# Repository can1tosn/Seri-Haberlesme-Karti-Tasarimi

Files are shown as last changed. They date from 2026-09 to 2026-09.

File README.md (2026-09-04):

# Seri-Haberlesme-Karti-Tasarimi
Altium Designer ile tasarlanmış; STM32F437 mikrodenetleyici tabanlı, çoklu haberleşme arayüzlerine (RS-485, RS-232, CAN Bus, Ethernet) ve RT7235 buck konvertör güç katına sahip 4 katmanlı endüstriyel donanım kartı tasarımı.

# Çoklu Arayüzlü Endüstriyel Haberleşme Kartı

Bu depo, RST Teknoloji'deki mühendislik stajım kapsamında Altium Designer kullanılarak sıfırdan tasarlanmış endüstriyel bir donanım kartına ait şematik, PCB dizgi (4-katman), üretim ve 3D model dosyalarını içermektedir.

## 🛠️ Donanım Özellikleri ve Temel Bileşenler
* **Mikrodenetleyici:** STM32F437 (Yüksek performanslı ARM Cortex-M4 çekirdek)
* **Güç Katı (Power Management):** RT7235GQW Senkron Buck Konvertör (12V giriş, kararlı 5V/3.3V çıkış, özel soft-start ve bootstrap filtrelemeli tasarım)
* **Endüstriyel Haberleşme Arayüzleri:** 
  * RS-485 / RS-422 (SN65HVD78DRBT transceiver ile 120 Ohm sonlandırmalı empedans kontrolü)
  * RS-232 (Çift kanallı iletişim)
  * CAN Bus (Otomotiv ve endüstri standartlarında veri yolu)
* **Ağ Bağlantısı:** LAN8742A Ethernet PHY (25 MHz yüksek kararlılıklı C0G kristal osilatör devresi ile)
* **Çevresel Sensörler:** BME280 (I2C/SPI destekli sıcaklık, nem ve basınç sensörü)

## 📂 Depo İçeriği ve İnceleme Dosyaları
Bu proje, sadece donanım mühendislerinin değil; yazılım, mekanik ve test ekiplerinin de kolayca inceleyebileceği evrensel formatları barındırır:

* **Altium Kaynak Dosyaları:** Geliştirmeye açık güncel şematik (`.SchDoc`), 4-katmanlı PCB (`.PcbDoc`) ve projeye özel kütüphane dosyaları.
* **BOM (Malzeme Listesi):** Üretim optimizasyonu (BOM Consolidation) sağlamak amacıyla pasif bileşenler ve yüksek hassasiyetli elemanlarla hazırlanmış üretime hazır Excel listesi.
* **📄 Akıllı PDF (Smart PDF):** Bilgisayarında Altium Designer kurulu olmayan kişilerin şematikleri interaktif olarak inceleyebilmesi için oluşturulmuştur. (*PDF üzerinden pinlere veya komponentlere tıklayarak bağlantıları (net) takip edebilirsiniz.*)
* **🧊 3D STEP Modeli:** Kartın mekanik (kutu içi) entegrasyon testleri ve SolidWorks gibi CAD programlarında incelenebilmesi için `.step` formatında 3 boyutlu katı modeli.

## 🔍 Tarayıcı Üzerinden İnteraktif İnceleme (Program Kurulumsuz)
Bilgisayarınıza herhangi bir program indirmeden projenin 3 boyutlu halini ve PCB katman yollarını incelemek isterseniz:
1. Depodaki kaynak dosyaları bilgisayarınıza indirin (ZIP olarak).
2. [Altium 365 Online Viewer](https://www.altium.com/viewer/) adresine gidin.
3. Dosyaları ekrana sürükleyip bırakarak projeyi web tarayıcınız üzerinden tüm detaylarıyla inceleyin.

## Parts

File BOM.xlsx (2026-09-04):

Designator | Description | MPN | Quantity
B1 | TRANS NPN 40V 0.2A SOT23-3 | MMBT3904 | 1
C1, C8 | CON SMD 402 | CL05A104KA5NNNC | 2
C2, C3, C4, C5, C6, C7, C11, C16, C19, C20, C21, C31, C33 | CAP SMD 402 | CL05A104KA5NNNC | 13
C9, C10, C24 | CON SMD 0603 | GRM188R61E106MA73D | 3
C12 | CAP SMD 402 | C0603C392J3GACTU | 1
C13, C14 | CAP SMD 0805 | CL10A226MO7JZNC | 2
C15 | CAP SMD 402 | C0402C153J5RECTU | 1
C17, C23, C53, C54, C61 | CAP SMD 402 | GRM155R6YA105KE11D | 5
C18, C63 | CON SMD 402 | CL05A104KA5NNNC | 2
C22, C32 | CAP SMD 402 | C1005X5R1V225K050BC | 2
C25 | CAP SMD 402 | C0402C103K5RECAUTO | 1
C26, C27 | CAP SMD 402 | GCM1555C1H470JA16D | 2
C28, C30, C36, C37, C38, C39, C40, C41, C42, C43, C44, C45, C46, C47, C48, C50, C51, C52, C55, C56, C57, C58 | CAP SMD 402 | CL05A104KA5NNNC | 22
C29 | CAP SMD 0603 | GRM188R61E475KE11D | 1
C34, C35, C59, C62 | CAP SMD 402 | GRM1555C1H150JA01D | 4
C49 | CAP SMD 0603 | GRM188R61E106MA73D | 1
C60 | CAP SMD 402 | GRM1555C1H471JA01D | 1
C64 | CAP SMD 402 | C0402C472K5RECAUTO | 1
D1, D2, D3, D4, D5 | LED RED CLEAR 0603 SMD | 150060RS75000 | 5
D6 | DIODE SCHOTTKY 40V 1A DO214AC | SS14 | 1
J1 | CONN HEADER R/A 8POS 2.54MM | 0901362108 | 1
J2, J3, J7, J8 | CONN HEADER R/A 2POS 2.54MM | 0901362102 | 4
J4, J6 | CONN HEADER R/A 4POS 2.54MM | 0901362104 | 2
J5 | CONN RCPT USB2.0 TYPEA 4P SMD RA | 87583-3010RPALF | 1
J9 | CONN JACK 1PORT PCB | ARJM11C7-009-AB-EW2 | 1
J10 | CONN RCPT USB2.0 MICRO B SMD R/A | 10118192-0001LF | 1
J11 | CONN HEADER R/A 2POS 2.54MM | 0901362102 | 1
J12 | CONN HEADER R/A 10POS 2.54MM | 0901362110 | 1
J13 | WR-PHD 2.54 MM SOCKET HEADER 4 P | 61300411821 | 1
L1 | FIXED IND 2.2UH 850MA 175.5 MOHM | BRL2518T2R2M | 1
M1 | MOSFET N-CH 12V 2.1A 3PICOSTAR | IRLML6402 | 1
R1 | RES SMD 0402 |  | 1
R2 | RES SMD 0402 | ERJ-2RKF1003X | 1
R3 | RES SMD 0402 | ERA-2AEB183X | 1
R4, R5, R12 | RES SMD 0402 | ERJ-2RKF1200X | 3
R6 | RES SMD 0603 | MI0603J601R-10 | 1
R7, R8 | RES SMD 0402 | RC0402FR-0727RL | 2
R9, R10, R28 | RES SMD 0402 | RMCF0402FT4K70 | 3
R11, R13, R14, R15, R16, R17, R18, R20, R29, R37 | RES SMD 0402 | RNCF0402BTE10K0 | 10
R19 | RES SMD 0402 | CR0402FC1KS001 | 1
R21, R27 | RES SMD 0402 | RMCF0402FT270R | 2
R22, R23, R24, R25 | RES SMD 0402 | RG1005N-49R9-W-T1 | 4
R26 | RES SMD 0603 | RT0603BRD0712K1L | 1
R30 | RES SMD 0402 | CR0402JC1MS001 | 1
R31 | RES SMD 0805 | RG2012L-472-L-T05 | 1
R32, R33, R34, R35, R36 | RES SMD 0402 | RC0402FR-13300RL | 5
SW2 | Tactile Switch, SPST-NO, 0.05 A, 12 V, -25 to 70 degC, 2-Pin SMD, RoHS | B3U-1000P | 1
U1 | IC TRANSCEIVER FULL 1/1 16SSOP (±5V i±15V - 3kΩ 7kΩ) | MAX3221EIDBR | 1
U2 | IC TRANSCEIVER HALF 1/1 8SON (-7V +12V - 54 Ω) | SN65HVD78DRBT | 1
U3 | IC REG BUCK ADJ 5A 10WDFN | RT7235GQW | 1
U4 | IC TRANSCEIVER 1/1 8SOIC | MCP2562FD-E/SN | 1
U5 | SENSOR PRESSURE HUMIDITY TEMP | BME280 | 1
U6 | IC TRANSCEIVER FULL 1/1 8SOIC | SP3077EEN-L | 1
U7 | MCU 32-bit STM32F ARM Cortex M4 RISC 2048KB Flash 2.5V/3.3V 144-Pin LQFP | STM32F437ZIT6 | 1
U8 | IC REG LINEAR 3.3V 500MA 6-WSON | TLV75533PDRVR | 1
U9 | IC USB SERIAL BASIC UART 12DFN (0V - 3.3V, 27Ω - 90Ω) | FT234XD-R | 1
U10 | IC TRANSCEIVER HALF 1/1 8SON | SN65HVD78DRBT | 1
U11 | IC TRANSCEIVER FULL 1/1 24SQFN | LAN8742AI-CZ-TR | 1
U12 | TVS DIODE 5.25VWM 17VC SOT23-6 | USBLC6-2SC6 | 1
U13 | IC PWR SWITCH N-CHAN 1:1 SOT23-5 | STMPS2141STR | 1
X1, X2 | CRYSTAL 25.0000MHZ 10PF SMD | RH100-25.000-10-F-1010-EXT-TR | 2

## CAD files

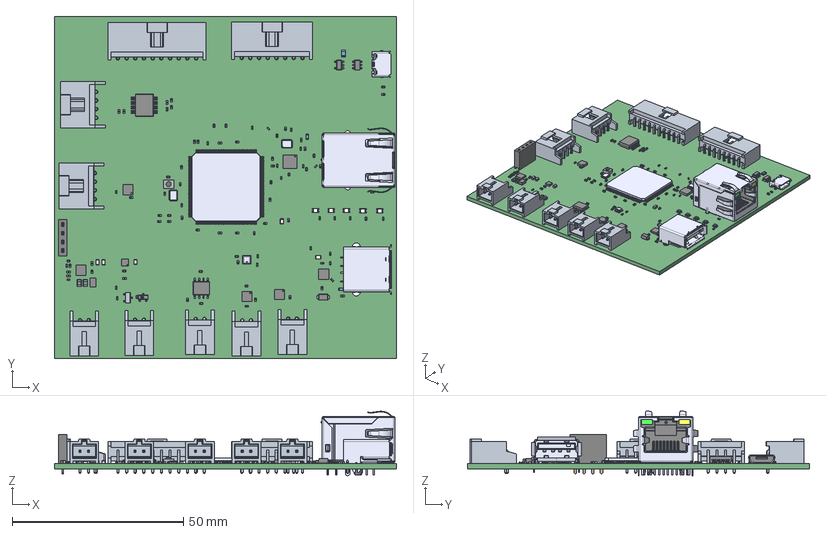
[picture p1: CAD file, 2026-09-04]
PCB1.step
100.0 x 100.0 x 18.9 mm
6130xx11821_PIN x 4
87583-2010RPLF--3DModel-STEP-533217
cap_UMK105CG080CV-F_TAY x 57
11H_HOUSING_1^11H_HOUSING_LED_ASM_7_ASM_ASM_11H_HOUSING_LED_COVER_ASM_ 1_ASM_ASM_11H_HOUSING_MODULE_ASM_1_ASM_ASM_11H_ASSEMBLE_BOTTOM_PCB_ASM_ 2_A_ASM_11H_ASSY_
11H_LED_LEFT_2^11H_HOUSING_LED_ASM_7_ASM_ASM_11H_HOUSING_LED_COVER_ASM_ 1_ASM_ASM_11H_HOUSING_MODULE_ASM_1_ASM_ASM_11H_ASSEMBLE_BOTTOM_PCB_ASM_ 2_A_ASM_11H_ASSY
11H_LED_RIGHT_3^11H_HOUSING_LED_ASM_7_ASM_ASM_11H_HOUSING_LED_COVER_ ASM_1_ASM_ASM_11H_HOUSING_MODULE_ASM_1_ASM_ASM_11H_ASSEMBLE_BOTTOM_PCB_ ASM_2_A_ASM_11H_ASS
PCB_3^PCBA_ASM_3_ASM_ASM_11H_MODULE_PCBA_ASM_3_AF0_ASM_ASM_11H_MODULE_ INSERT_ASM_5_ASM_ASM_11H_HOUSING_MODULE_ASM_1_ASM_ASM_11H_ASSEMBLE_ BOTTOM_PCB_ASM_2_A_AS
4D03_3^PCBA_ASM_3_ASM_ASM_11H_MODULE_PCBA_ASM_3_AF0_ASM_ASM_11H_MODULE_ INSERT_ASM_5_ASM_ASM_11H_HOUSING_MODULE_ASM_1_ASM_ASM_11H_ASSEMBLE_ BOTTOM_PCB_ASM_2_A_A
C_1206_3^PCBA_ASM_3_ASM_ASM_11H_MODULE_PCBA_ASM_3_AF0_ASM_ASM_11H_ MODULE_INSERT_ASM_5_ASM_ASM_11H_HOUSING_MODULE_ASM_1_ASM_ASM_11H_ ASSEMBLE_BOTTOM_PCB_ASM_2_A
MANIFOLD_SOLID_BREP_57001^CP_1_3_ASM_ASM_MODULE_CASE_11H_ASM_9_AF0_ASM_ ASM_MODULE_11H_ASM_3_AF0_ASM_ASM_11H_MODULE_PCBA_ASM_3_AF0_ASM_ASM_11H_ MODULE_INSERT_AS
MANIFOLD_SOLID_BREP_57246^CP_1_3_ASM_ASM_MODULE_CASE_11H_ASM_9_AF0_ASM_ ASM_MODULE_11H_ASM_3_AF0_ASM_ASM_11H_MODULE_PCBA_ASM_3_AF0_ASM_ASM_11H_ MODULE_INSERT_AS
MANIFOLD_SOLID_BREP_57491^CP_1_3_ASM_ASM_MODULE_CASE_11H_ASM_9_AF0_ASM_ ASM_MODULE_11H_ASM_3_AF0_ASM_ASM_11H_MODULE_PCBA_ASM_3_AF0_ASM_ASM_11H_ MODULE_INSERT_AS
MANIFOLD_SOLID_BREP_57736^CP_1_3_ASM_ASM_MODULE_CASE_11H_ASM_9_AF0_ASM_ ASM_MODULE_11H_ASM_3_AF0_ASM_ASM_11H_MODULE_PCBA_ASM_3_AF0_ASM_ASM_11H_ MODULE_INSERT_AS
MANIFOLD_SOLID_BREP_57981^CP_1_3_ASM_ASM_MODULE_CASE_11H_ASM_9_AF0_ASM_ ASM_MODULE_11H_ASM_3_AF0_ASM_ASM_11H_MODULE_PCBA_ASM_3_AF0_ASM_ASM_11H_ MODULE_INSERT_AS
MANIFOLD_SOLID_BREP_58226^CP_1_3_ASM_ASM_MODULE_CASE_11H_ASM_9_AF0_ASM_ ASM_MODULE_11H_ASM_3_AF0_ASM_ASM_11H_MODULE_PCBA_ASM_3_AF0_ASM_ASM_11H_ MODULE_INSERT_AS
MANIFOLD_SOLID_BREP_58517^CP_2_6_ASM_ASM_MODULE_CASE_11H_ASM_9_AF0_ASM_ ASM_MODULE_11H_ASM_3_AF0_ASM_ASM_11H_MODULE_PCBA_ASM_3_AF0_ASM_ASM_11H_ MODULE_INSERT_AS
MANIFOLD_SOLID_BREP_58762^CP_2_6_ASM_ASM_MODULE_CASE_11H_ASM_9_AF0_ASM_ ASM_MODULE_11H_ASM_3_AF0_ASM_ASM_11H_MODULE_PCBA_ASM_3_AF0_ASM_ASM_11H_ MODULE_INSERT_AS
MANIFOLD_SOLID_BREP_59007^CP_2_6_ASM_ASM_MODULE_CASE_11H_ASM_9_AF0_ASM_ ASM_MODULE_11H_ASM_3_AF0_ASM_ASM_11H_MODULE_PCBA_ASM_3_AF0_ASM_ASM_11H_ MODULE_INSERT_AS
MANIFOLD_SOLID_BREP_59252^CP_2_6_ASM_ASM_MODULE_CASE_11H_ASM_9_AF0_ASM_ ASM_MODULE_11H_ASM_3_AF0_ASM_ASM_11H_MODULE_PCBA_ASM_3_AF0_ASM_ASM_11H_ MODULE_INSERT_AS
MODULE_CASE_5_AF0^MODULE_CASE_11H_ASM_9_AF0_ASM_ASM_MODULE_11H_ASM_3_ AF0_ASM_ASM_11H_MODULE_PCBA_ASM_3_AF0_ASM_ASM_11H_MODULE_INSERT_ASM_5_ ASM_ASM_11H_HOUSING
CP_3_GND_1067_3^MODULE_CASE_11H_ASM_9_AF0_ASM_ASM_MODULE_11H_ASM_3_AF0_ ASM_ASM_11H_MODULE_PCBA_ASM_3_AF0_ASM_ASM_11H_MODULE_INSERT_ASM_5_ASM_ ASM_11H_HOUSING_M
MANIFOLD_SOLID_BREP_60100_AF0^CORE_T_3_AF0_ASM_ASM_COIL_ASM_3_AF0_ASM_ ASM_MODULE_11H_ASM_3_AF0_ASM_ASM_11H_MODULE_PCBA_ASM_3_AF0_ASM_ASM_11H_ MODULE_INSERT_ASM
MANIFOLD_SOLID_BREP_60561_AF0^CORE_T_3_AF0_ASM_ASM_COIL_ASM_3_AF0_ASM_ ASM_MODULE_11H_ASM_3_AF0_ASM_ASM_11H_MODULE_PCBA_ASM_3_AF0_ASM_ASM_11H_ MODULE_INSERT_ASM
MANIFOLD_SOLID_BREP_61022_AF0^CORE_T_3_AF0_ASM_ASM_COIL_ASM_3_AF0_ASM_ ASM_MODULE_11H_ASM_3_AF0_ASM_ASM_11H_MODULE_PCBA_ASM_3_AF0_ASM_ASM_11H_ MODULE_INSERT_ASM
MANIFOLD_SOLID_BREP_61483_AF0^CORE_T_3_AF0_ASM_ASM_COIL_ASM_3_AF0_ASM_ ASM_MODULE_11H_ASM_3_AF0_ASM_ASM_11H_MODULE_PCBA_ASM_3_AF0_ASM_ASM_11H_ MODULE_INSERT_ASM
MANIFOLD_SOLID_BREP_61944_AF0^CORE_T_3_AF0_ASM_ASM_COIL_ASM_3_AF0_ASM_ ASM_MODULE_11H_ASM_3_AF0_ASM_ASM_11H_MODULE_PCBA_ASM_3_AF0_ASM_ASM_11H_ MODULE_INSERT_ASM
MANIFOLD_SOLID_BREP_62405_AF0^CORE_T_3_AF0_ASM_ASM_COIL_ASM_3_AF0_ASM_ ASM_MODULE_11H_ASM_3_AF0_ASM_ASM_11H_MODULE_PCBA_ASM_3_AF0_ASM_ASM_11H_ MODULE_INSERT_ASM
MANIFOLD_SOLID_BREP_62866_AF0^CORE_T_3_AF0_ASM_ASM_COIL_ASM_3_AF0_ASM_ ASM_MODULE_11H_ASM_3_AF0_ASM_ASM_11H_MODULE_PCBA_ASM_3_AF0_ASM_ASM_11H_ MODULE_INSERT_ASM
MANIFOLD_SOLID_BREP_63327_AF0^CORE_T_3_AF0_ASM_ASM_COIL_ASM_3_AF0_ASM_ ASM_MODULE_11H_ASM_3_AF0_ASM_ASM_11H_MODULE_PCBA_ASM_3_AF0_ASM_ASM_11H_ MODULE_INSERT_ASM
MANIFOLD_SOLID_BREP_63788_AF0^CORE_T_3_AF0_ASM_ASM_COIL_ASM_3_AF0_ASM_ ASM_MODULE_11H_ASM_3_AF0_ASM_ASM_11H_MODULE_PCBA_ASM_3_AF0_ASM_ASM_11H_ MODULE_INSERT_ASM
MANIFOLD_SOLID_BREP_64249_AF0^CORE_T_3_AF0_ASM_ASM_COIL_ASM_3_AF0_ASM_ ASM_MODULE_11H_ASM_3_AF0_ASM_ASM_11H_MODULE_PCBA_ASM_3_AF0_ASM_ASM_11H_ MODULE_INSERT_ASM
MANIFOLD_SOLID_BREP_64710_AF0^CORE_T_3_AF0_ASM_ASM_COIL_ASM_3_AF0_ASM_ ASM_MODULE_11H_ASM_3_AF0_ASM_ASM_11H_MODULE_PCBA_ASM_3_AF0_ASM_ASM_11H_ MODULE_INSERT_ASM
MANIFOLD_SOLID_BREP_65116_AF0^CORE_K_3_AF0_ASM_ASM_COIL_ASM_3_AF0_ASM_ ASM_MODULE_11H_ASM_3_AF0_ASM_ASM_11H_MODULE_PCBA_ASM_3_AF0_ASM_ASM_11H_ MODULE_INSERT_ASM
MANIFOLD_SOLID_BREP_65577^CORE_K_3_AF0_ASM_ASM_COIL_ASM_3_AF0_ASM_ASM_ MODULE_11H_ASM_3_AF0_ASM_ASM_11H_MODULE_PCBA_ASM_3_AF0_ASM_ASM_11H_ MODULE_INSERT_ASM_5_A
MANIFOLD_SOLID_BREP_66038_AF0^CORE_K_3_AF0_ASM_ASM_COIL_ASM_3_AF0_ASM_ ASM_MODULE_11H_ASM_3_AF0_ASM_ASM_11H_MODULE_PCBA_ASM_3_AF0_ASM_ASM_11H_ MODULE_INSERT_ASM
MANIFOLD_SOLID_BREP_66499_AF0^CORE_K_3_AF0_ASM_ASM_COIL_ASM_3_AF0_ASM_ ASM_MODULE_11H_ASM_3_AF0_ASM_ASM_11H_MODULE_PCBA_ASM_3_AF0_ASM_ASM_11H_ MODULE_INSERT_ASM
MANIFOLD_SOLID_BREP_66960_AF0^CORE_K_3_AF0_ASM_ASM_COIL_ASM_3_AF0_ASM_ ASM_MODULE_11H_ASM_3_AF0_ASM_ASM_11H_MODULE_PCBA_ASM_3_AF0_ASM_ASM_11H_ MODULE_INSERT_ASM
MANIFOLD_SOLID_BREP_67421_AF0^CORE_K_3_AF0_ASM_ASM_COIL_ASM_3_AF0_ASM_ ASM_MODULE_11H_ASM_3_AF0_ASM_ASM_11H_MODULE_PCBA_ASM_3_AF0_ASM_ASM_11H_ MODULE_INSERT_ASM
MANIFOLD_SOLID_BREP_67882^CORE_K_3_AF0_ASM_ASM_COIL_ASM_3_AF0_ASM_ASM_ MODULE_11H_ASM_3_AF0_ASM_ASM_11H_MODULE_PCBA_ASM_3_AF0_ASM_ASM_11H_ MODULE_INSERT_ASM_5_A
MANIFOLD_SOLID_BREP_68343^CORE_K_3_AF0_ASM_ASM_COIL_ASM_3_AF0_ASM_ASM_ MODULE_11H_ASM_3_AF0_ASM_ASM_11H_MODULE_PCBA_ASM_3_AF0_ASM_ASM_11H_ MODULE_INSERT_ASM_5_A
MANIFOLD_SOLID_BREP_68804^CORE_K_3_AF0_ASM_ASM_COIL_ASM_3_AF0_ASM_ASM_ MODULE_11H_ASM_3_AF0_ASM_ASM_11H_MODULE_PCBA_ASM_3_AF0_ASM_ASM_11H_ MODULE_INSERT_ASM_5_A
MANIFOLD_SOLID_BREP_69265^CORE_K_3_AF0_ASM_ASM_COIL_ASM_3_AF0_ASM_ASM_ MODULE_11H_ASM_3_AF0_ASM_ASM_11H_MODULE_PCBA_ASM_3_AF0_ASM_ASM_11H_ MODULE_INSERT_ASM_5_A
MANIFOLD_SOLID_BREP_69726^CORE_K_3_AF0_ASM_ASM_COIL_ASM_3_AF0_ASM_ASM_ MODULE_11H_ASM_3_AF0_ASM_ASM_11H_MODULE_PCBA_ASM_3_AF0_ASM_ASM_11H_ MODULE_INSERT_ASM_5_A
MANIFOLD_SOLID_BREP_60100_AF1^CORE_T_3_AF1_ASM_ASM_COIL_ASM_3_AF1_ASM_ ASM_MODULE_11H_ASM_3_AF0_ASM_ASM_11H_MODULE_PCBA_ASM_3_AF0_ASM_ASM_11H_ MODULE_INSERT_ASM
MANIFOLD_SOLID_BREP_62866_AF1^CORE_T_3_AF1_ASM_ASM_COIL_ASM_3_AF1_ASM_ ASM_MODULE_11H_ASM_3_AF0_ASM_ASM_11H_MODULE_PCBA_ASM_3_AF0_ASM_ASM_11H_ MODULE_INSERT_ASM
MANIFOLD_SOLID_BREP_63788_AF1^CORE_T_3_AF1_ASM_ASM_COIL_ASM_3_AF1_ASM_ ASM_MODULE_11H_ASM_3_AF0_ASM_ASM_11H_MODULE_PCBA_ASM_3_AF0_ASM_ASM_11H_ MODULE_INSERT_ASM
MANIFOLD_SOLID_BREP_64249_AF1^CORE_T_3_AF1_ASM_ASM_COIL_ASM_3_AF1_ASM_ ASM_MODULE_11H_ASM_3_AF0_ASM_ASM_11H_MODULE_PCBA_ASM_3_AF0_ASM_ASM_11H_ MODULE_INSERT_ASM
MANIFOLD_SOLID_BREP_63788_AF2^CORE_T_3_AF2_ASM_ASM_COIL_ASM_3_AF2_ASM_ ASM_MODULE_11H_ASM_3_AF0_ASM_ASM_11H_MODULE_PCBA_ASM_3_AF0_ASM_ASM_11H_ MODULE_INSERT_ASM
MANIFOLD_SOLID_BREP_64249_AF2^CORE_T_3_AF2_ASM_ASM_COIL_ASM_3_AF2_ASM_ ASM_MODULE_11H_ASM_3_AF0_ASM_ASM_11H_MODULE_PCBA_ASM_3_AF0_ASM_ASM_11H_ MODULE_INSERT_ASM
MANIFOLD_SOLID_BREP_62866_AF2^CORE_T_3_AF2_ASM_ASM_COIL_ASM_3_AF2_ASM_ ASM_MODULE_11H_ASM_3_AF0_ASM_ASM_11H_MODULE_PCBA_ASM_3_AF0_ASM_ASM_11H_ MODULE_INSERT_ASM
MANIFOLD_SOLID_BREP_60100_AF2^CORE_T_3_AF2_ASM_ASM_COIL_ASM_3_AF2_ASM_ ASM_MODULE_11H_ASM_3_AF0_ASM_ASM_11H_MODULE_PCBA_ASM_3_AF0_ASM_ASM_11H_ MODULE_INSERT_ASM
MANIFOLD_SOLID_BREP_63788_AF3^CORE_T_3_AF3_ASM_ASM_COIL_ASM_3_AF3_ASM_ ASM_MODULE_11H_ASM_3_AF0_ASM_ASM_11H_MODULE_PCBA_ASM_3_AF0_ASM_ASM_11H_ MODULE_INSERT_ASM
MANIFOLD_SOLID_BREP_64249_AF3^CORE_T_3_AF3_ASM_ASM_COIL_ASM_3_AF3_ASM_ ASM_MODULE_11H_ASM_3_AF0_ASM_ASM_11H_MODULE_PCBA_ASM_3_AF0_ASM_ASM_11H_ MODULE_INSERT_ASM
MANIFOLD_SOLID_BREP_60100_AF3^CORE_T_3_AF3_ASM_ASM_COIL_ASM_3_AF3_ASM_ ASM_MODULE_11H_ASM_3_AF0_ASM_ASM_11H_MODULE_PCBA_ASM_3_AF0_ASM_ASM_11H_ MODULE_INSERT_ASM
MANIFOLD_SOLID_BREP_62866_AF3^CORE_T_3_AF3_ASM_ASM_COIL_ASM_3_AF3_ASM_ ASM_MODULE_11H_ASM_3_AF0_ASM_ASM_11H_MODULE_PCBA_ASM_3_AF0_ASM_ASM_11H_ MODULE_INSERT_ASM
RJ_INSERT_BASE_3^RJ_INSERT_ASM_3_ASM_ASM_11H_MODULE_INSERT_ASM_5_ASM_ ASM_11H_HOUSING_MODULE_ASM_1_ASM_ASM_11H_ASSEMBLE_BOTTOM_PCB_ASM_2_A_ ASM_11H_ASSY_SHIELD_
MANIFOLD_SOLID_BREP_81250^RJ_TERMINAL_3_ASM_ASM_RJ_INSERT_ASM_3_ASM_ ASM_11H_MODULE_INSERT_ASM_5_ASM_ASM_11H_HOUSING_MODULE_ASM_1_ASM_ASM_ 11H_ASSEMBLE_BOTTOM_P
MANIFOLD_SOLID_BREP_82263^RJ_TERMINAL_3_ASM_ASM_RJ_INSERT_ASM_3_ASM_ ASM_11H_MODULE_INSERT_ASM_5_ASM_ASM_11H_HOUSING_MODULE_ASM_1_ASM_ASM_ 11H_ASSEMBLE_BOTTOM_P
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

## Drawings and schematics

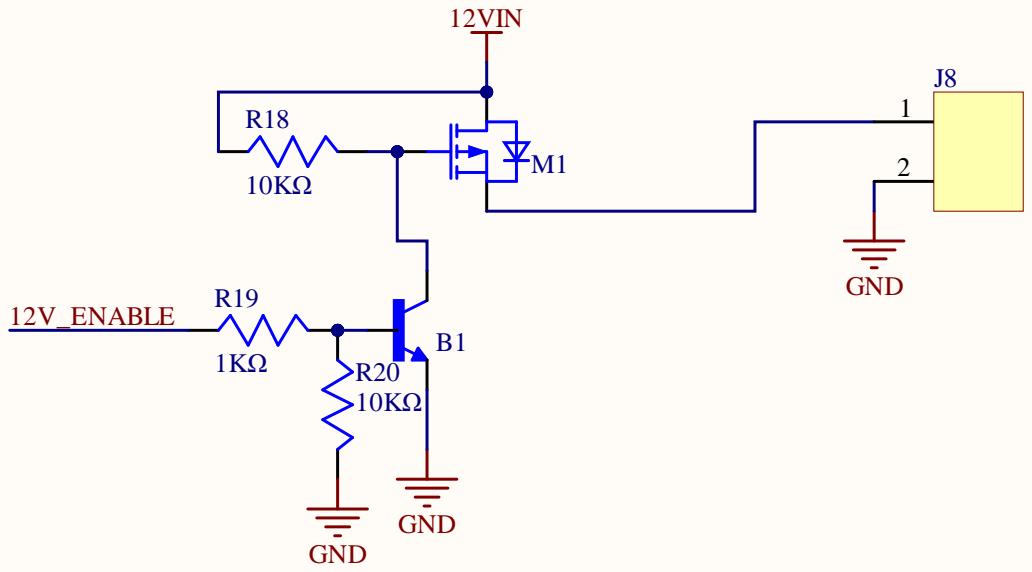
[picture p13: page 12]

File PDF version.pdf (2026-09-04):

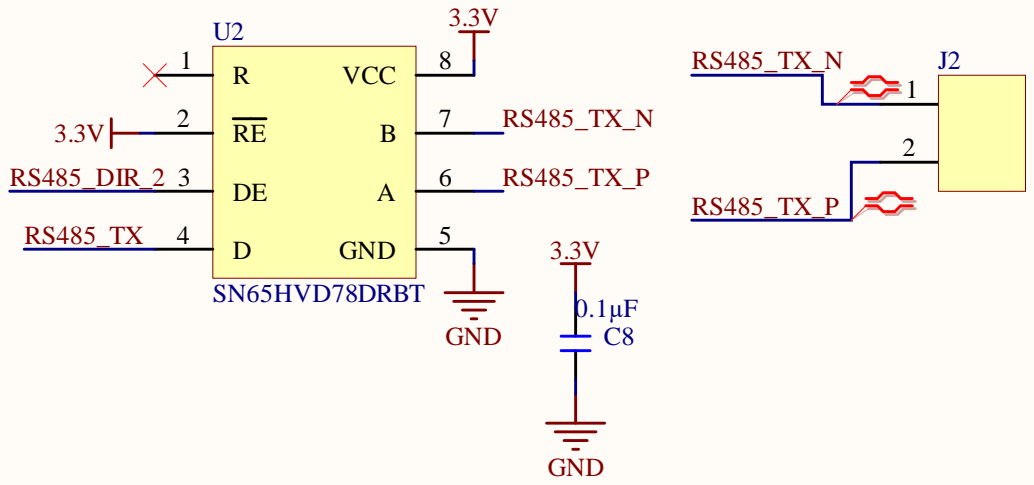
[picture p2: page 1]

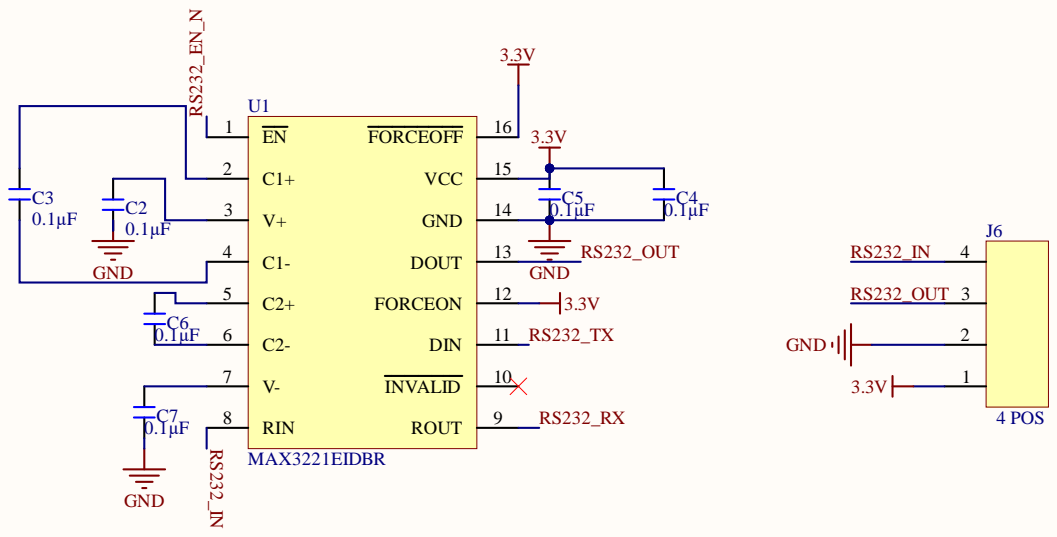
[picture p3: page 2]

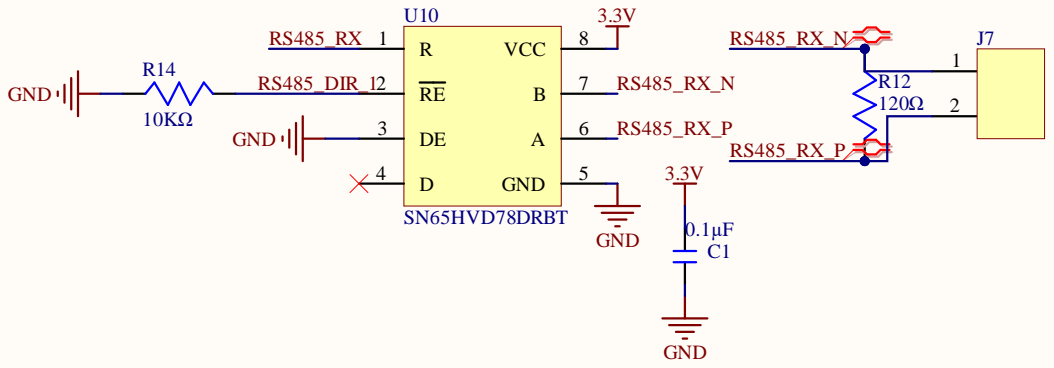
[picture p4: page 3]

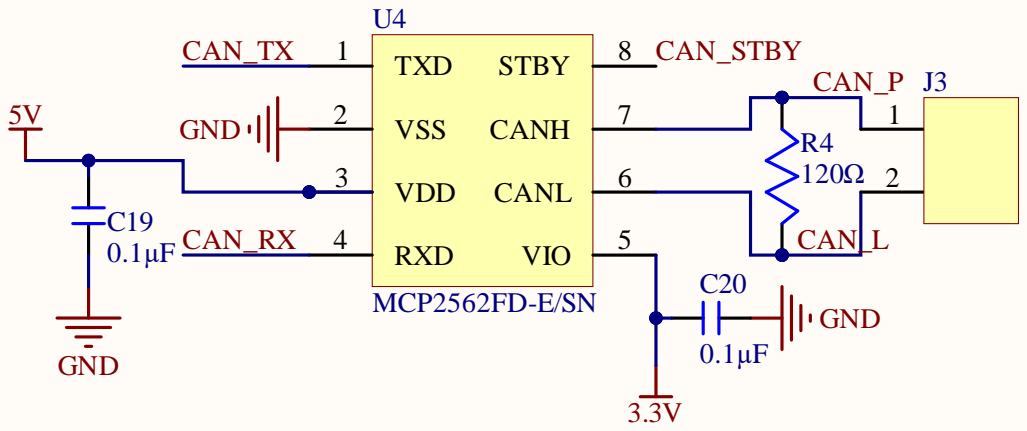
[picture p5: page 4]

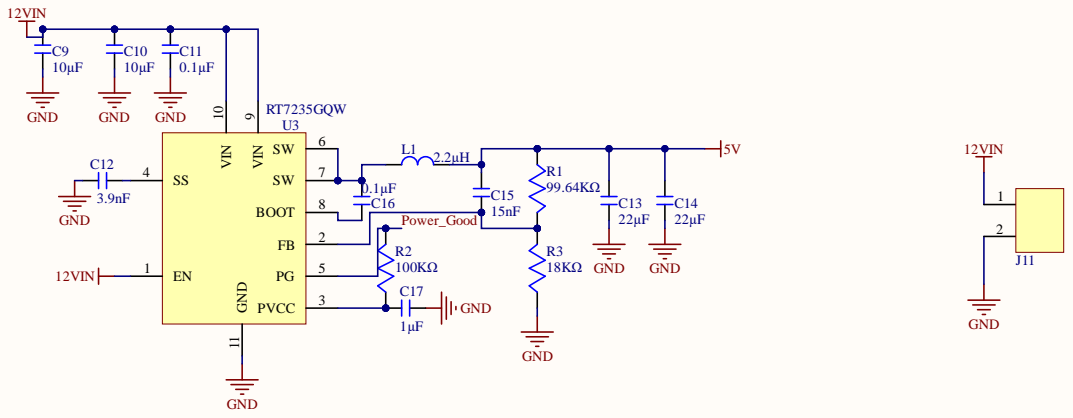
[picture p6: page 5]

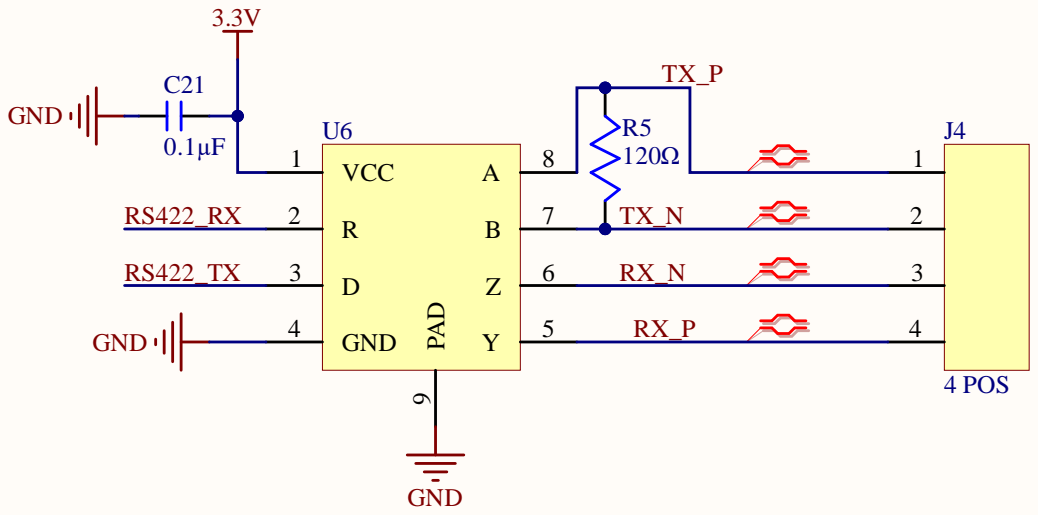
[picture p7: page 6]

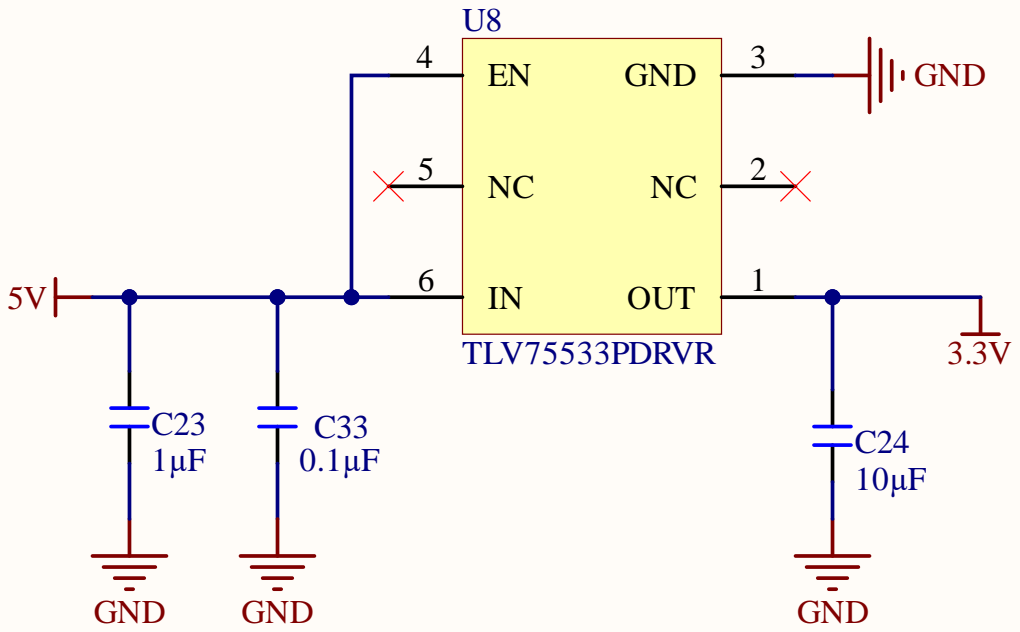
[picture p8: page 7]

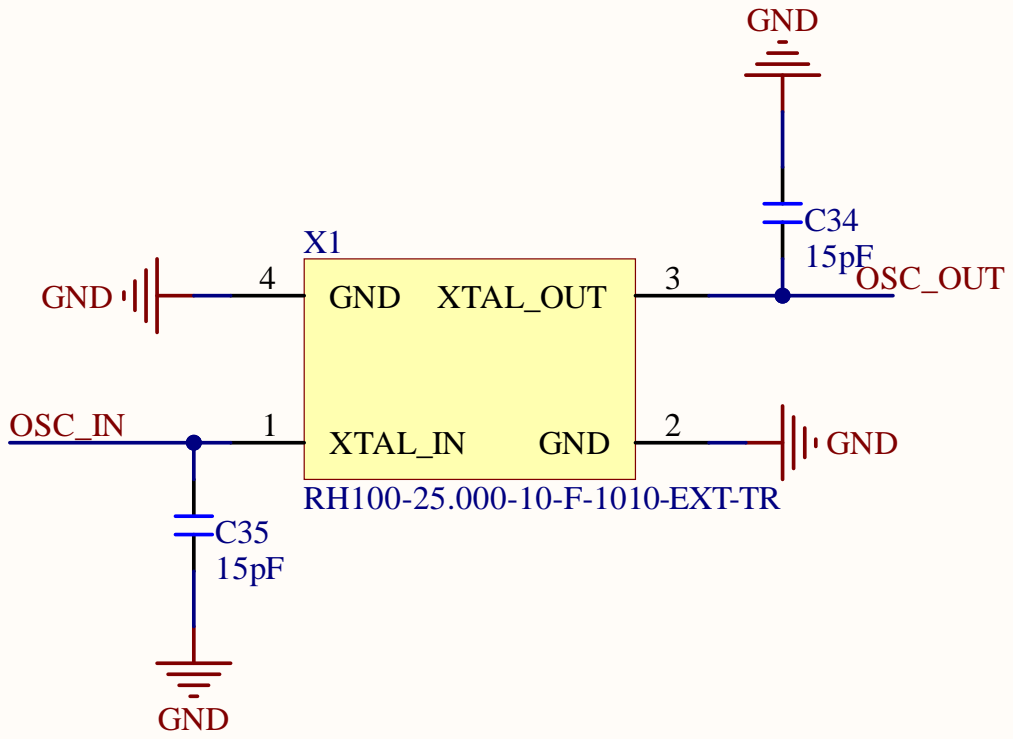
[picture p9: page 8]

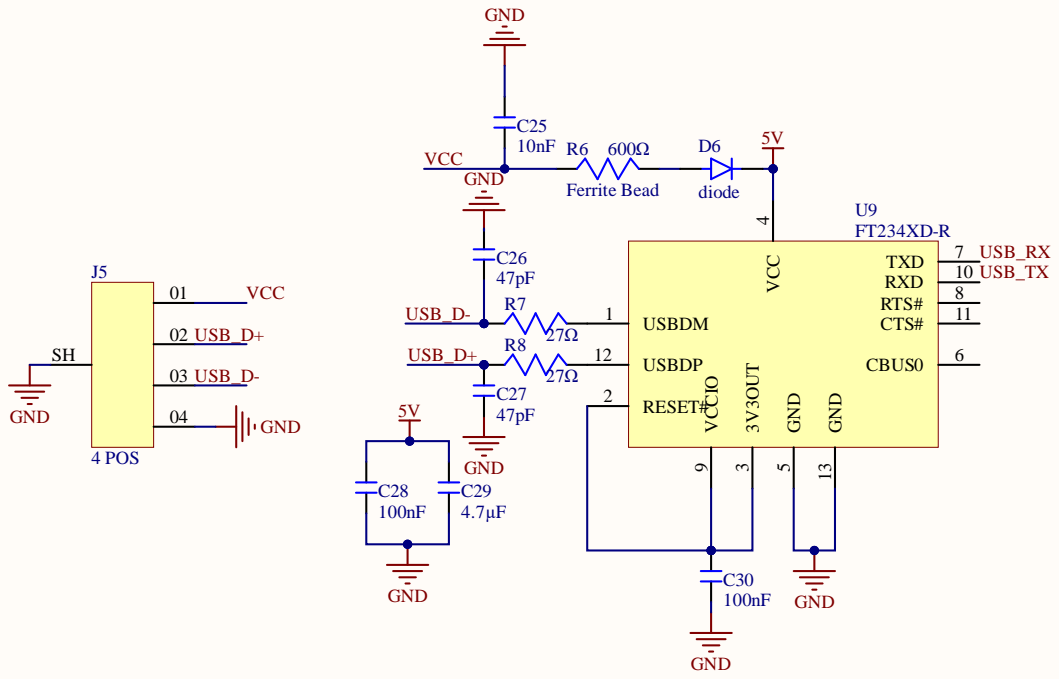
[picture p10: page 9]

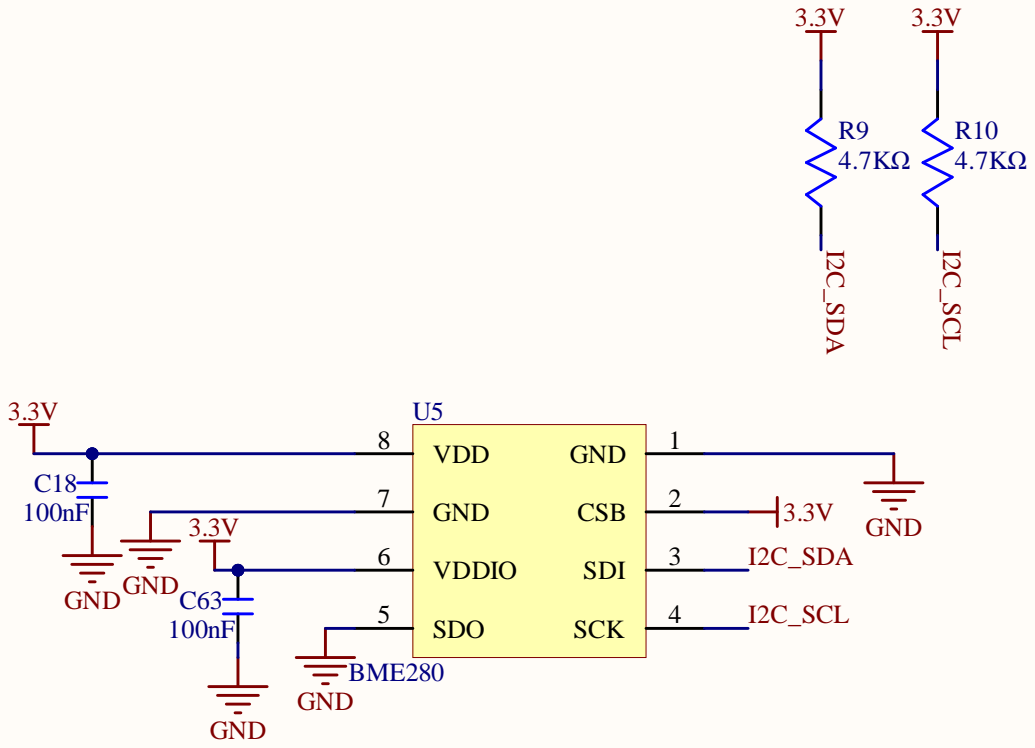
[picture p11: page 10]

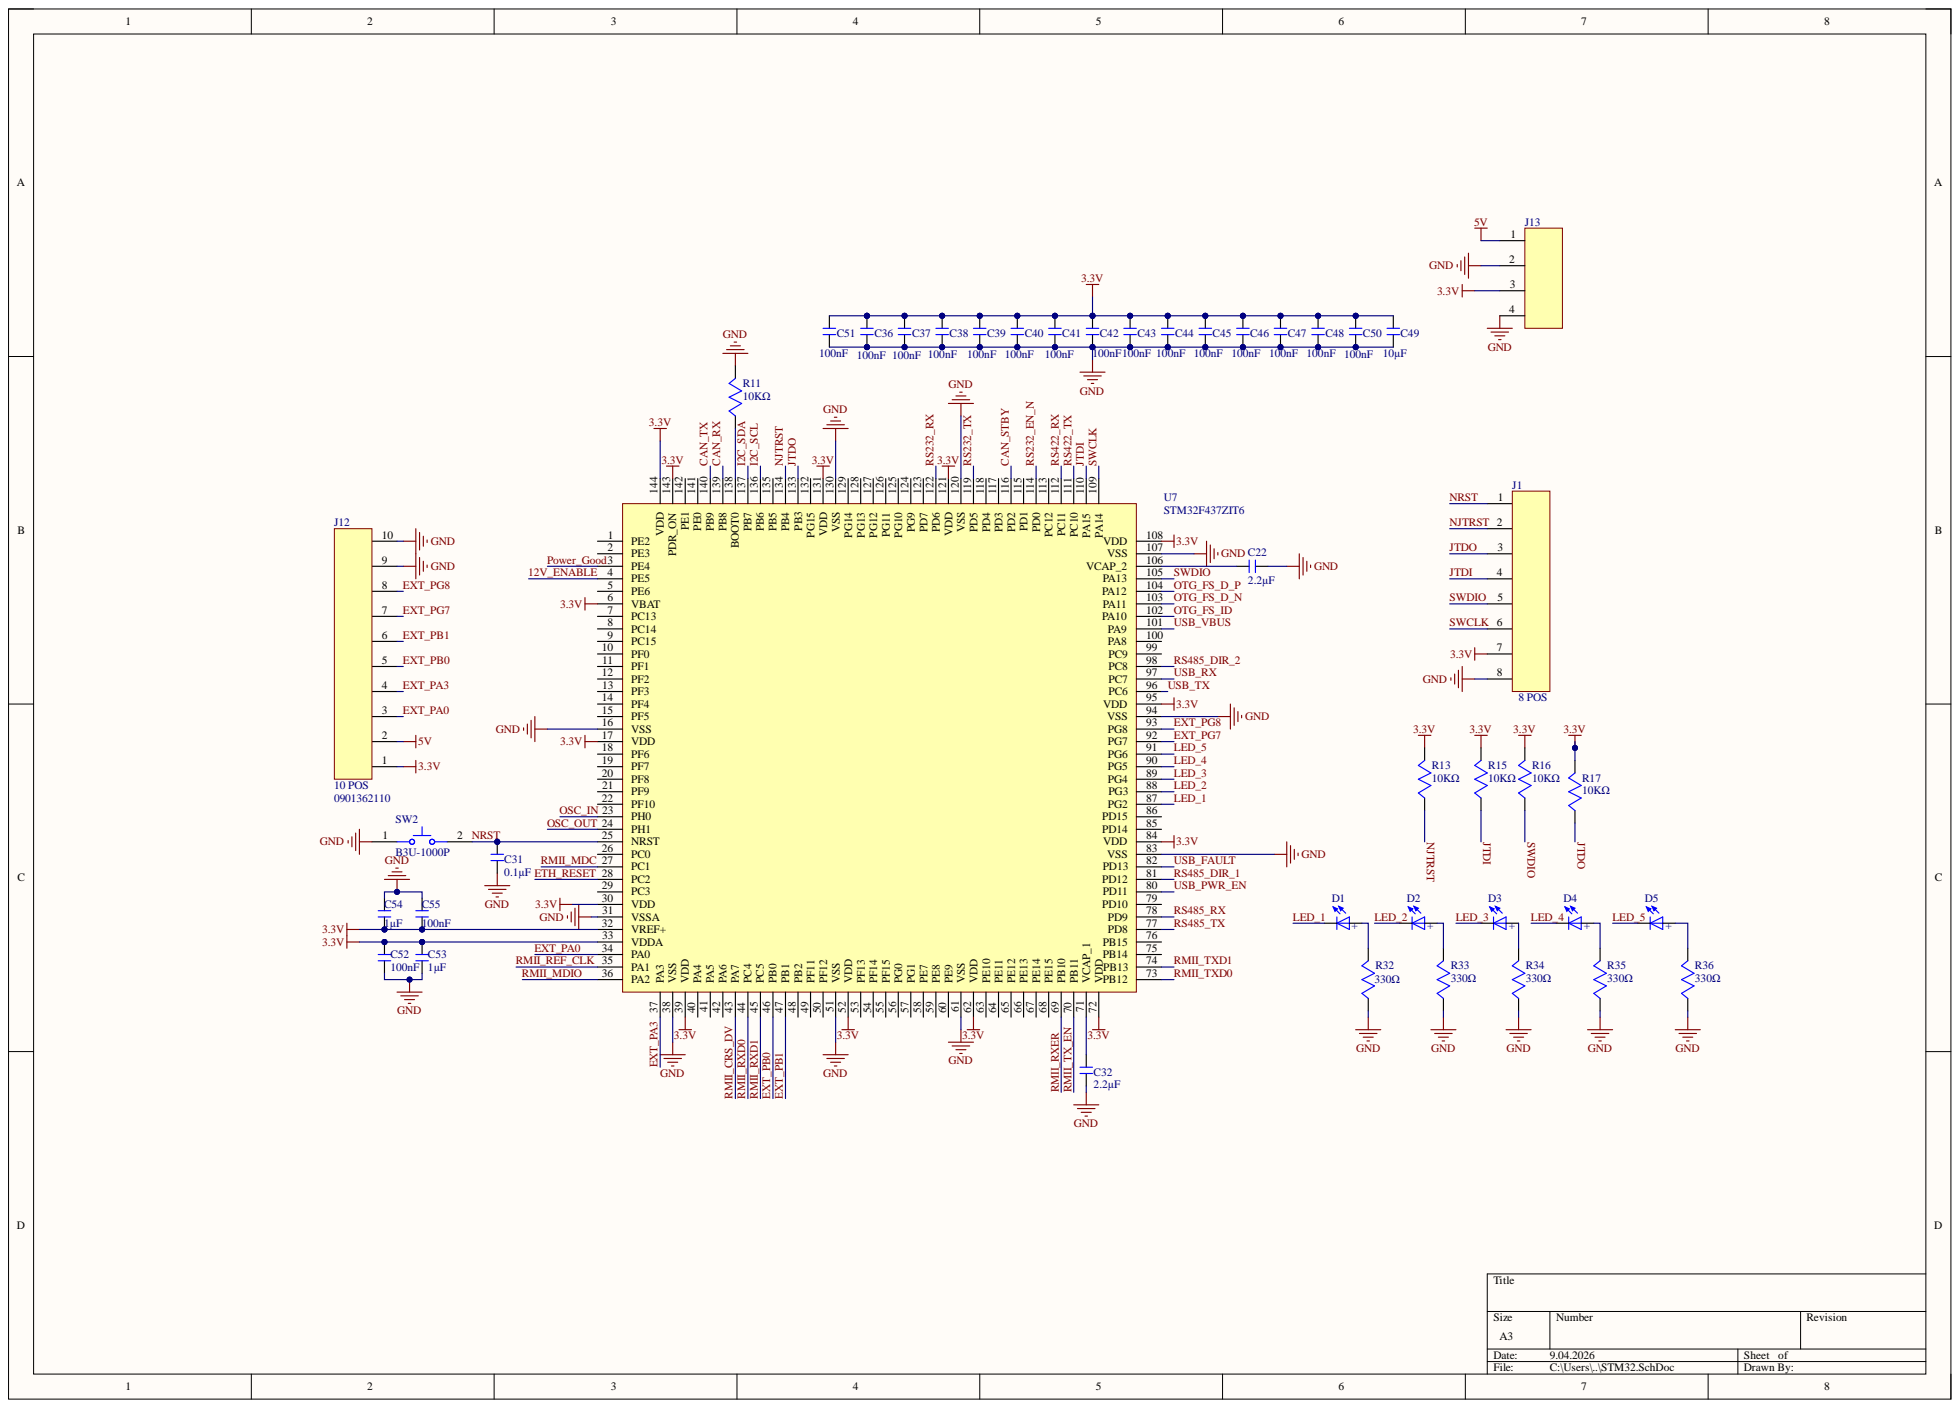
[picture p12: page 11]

108 A14 109 PA15 110 PC10 111 PC11 112 PC12 113 PD0 114 PD1 115 PD2 116 PD3 117 PD4 118 PD5 119 VSS 120 VDD 121 PD6 122 PD7 123 PG9 124 PG10 125 PG11 126 PG12 127 PG13 128 PG14 129 VSS 130 VDD 131 PG15 132 PB3 133 PB4 134 PB5 135 PB6 136 PB7 137 BOOT0 138 PB8 139 PB9 140 PE0 141 PE1 142 PDR_ON 143 VDD 144
